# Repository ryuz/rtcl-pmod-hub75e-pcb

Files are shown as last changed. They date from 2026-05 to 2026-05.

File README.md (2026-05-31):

# HUB-75E LEDパネルを PMOD １個で駆動する基板

## 概要

HUB75E 形式の LED パネルを PMOD １個で駆動するための変換基板です。

Sipeed さんの [PMOD_HUB75E](https://wiki.sipeed.com/hardware/en/tang/tang-PMOD/FPGA_PMOD.html) だと PMOD コネクタが２個必要で、KV260 などのように PMOD コネクタが１個しかない FPGA ボードでは利用できません。

そこで PMOD 一個からデュアルエッジでデータを出して 64x64 の LED パネルを駆動するための基板を設計しました。

## 変換基板のイメージ

下記のような変換基板です。

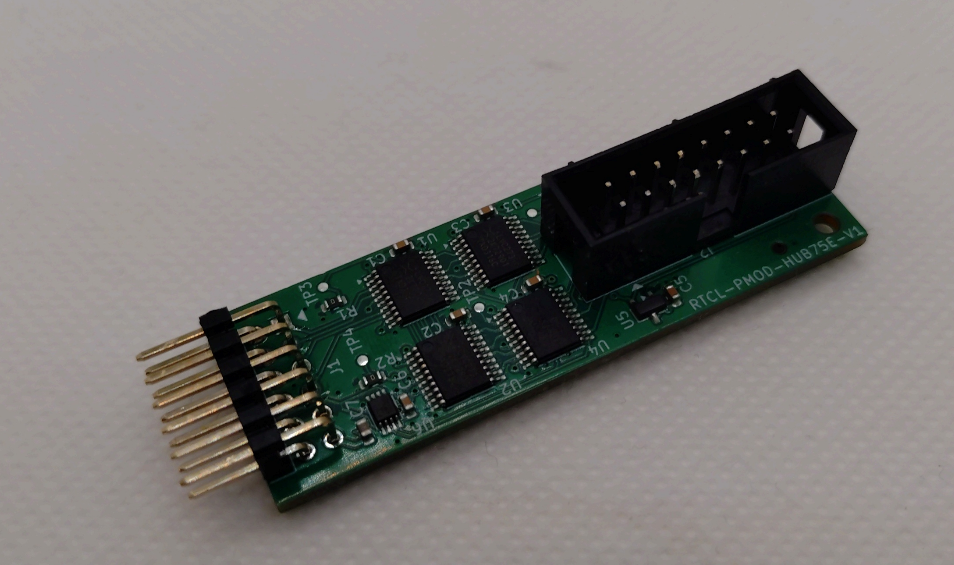
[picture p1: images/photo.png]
写真


PMOD コネクタ一個から HUB-75E LED パネルを駆動します。

## 各種データ

Ver1 の 回路図は[こちら](rtcl-pmod-hub75e-v1.pdf)です。

[KiCAD](https://www.kicad.org/) version 10.0.1 で設計しております。

[JLCPCB](https://jlcpcb.com/) さんの4層基板で製造を想定しております。

手元での試作は JLCPCB さんの PCBA で行っており、各自で製造される場合は必要に応じて部品を選定ください。

## 動作テスト

下記のプロジェクトなどで動作テストを行っております。

- https://github.com/ryuz/rtcl-designs/tree/develop/projects/kv260/kv260_rtcl_hub75e_sample

LED パネルの表示確認や各種パラメータの調整を行っております。

## 免責事項

本設計データは、研究開発用の試作実験に用するものであり、利用に際して発生した如何なる損害も作者は補償いたしませんので予めご了承ください。

## ライセンス(License)

本設計データは、[クリエイティブ・コモンズ 表示-非営利 4.0 国際 ライセンス](https://creativecommons.org/licenses/by-nc/4.0/deed.ja)の下で提供されています。

製造した本基板の販売や配布を行わない限りは、趣味や研究開発用途でご自由にお使いいただく事が出来ます。
また、商用に製造販売を希望される場合は、別途ライセンス契約を作者までご相談ください。

## 作者情報

渕上 竜司(Ryuji Fuchikami)
[リアルタイムコンピューティング研究所](https://rtc-lab.com/)

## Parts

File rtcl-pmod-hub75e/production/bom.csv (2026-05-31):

Designator | Footprint | Quantity | Value | LCSC Part #
C1, C2, C3, C4, C5, C6 | 0603 | 6 | 0.1uF
C7 | 0603 | 1 | 10uF
J1 | PH_02x06_2.54mm | 1 | PMOD | C124371
J2 | PH_02x08_2.54mm | 1 | HUB75E | C7430313
J3 | PinHeader_1x02_P2.54mm_Vertical | 1 | Conn_01x02
R1, R2 | 0603 | 2 | 0
R3 | 0603 | 1 | 10k
SW1 | SW_OS102011MS2QN1 | 1 | OS102011MS2QN1 | C221829
TP1, TP2, TP3, TP4 | TestPoint_Pad_D1.0mm | 4 | TestPoint
U1, U2, U3, U4 | TSSOP-20_4.4x6.5mm_P0.65mm | 4 | 74LVC273 | C456144
U5 | SOT-23-3 | 1 | APX803D-29SAG-7 | C460555
U6 | VSSOP-8_2.3x2mm_P0.5mm | 1 | SN74LVC2G86DCUR | C507252

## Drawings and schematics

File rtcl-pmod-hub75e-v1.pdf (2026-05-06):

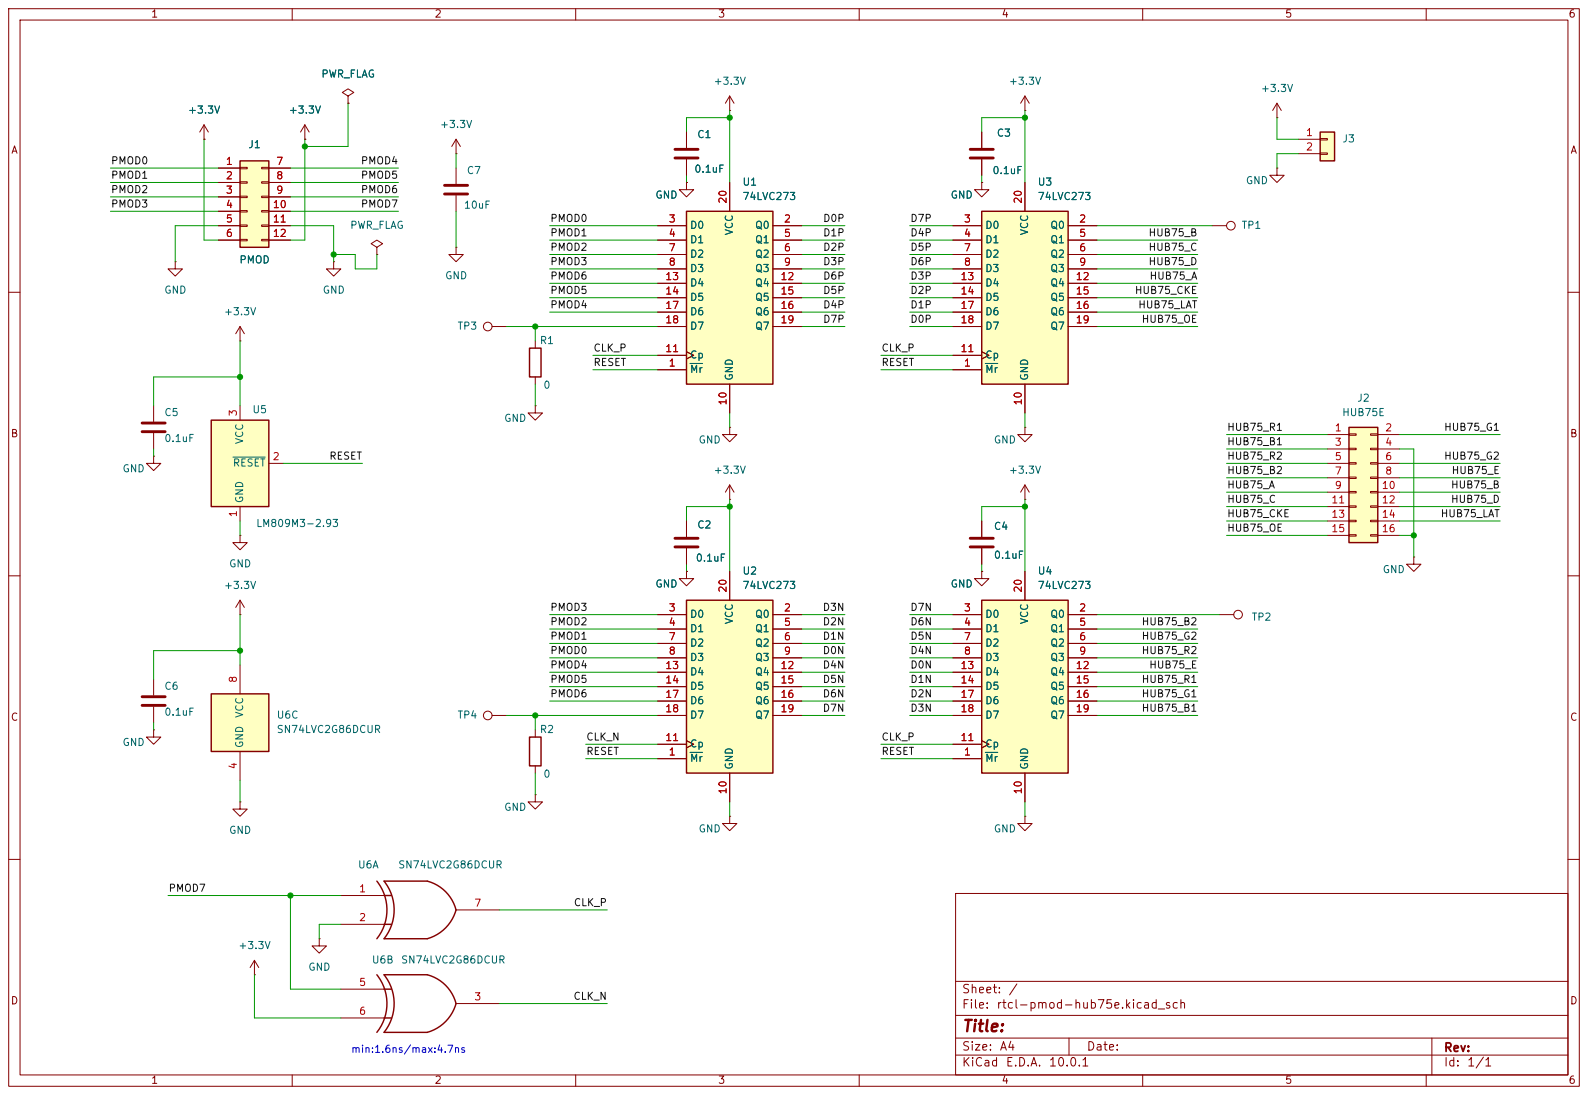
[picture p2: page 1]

Size: A4 | Rev:
KiCad E.D.A. 10.0.1 | Id: 1/1

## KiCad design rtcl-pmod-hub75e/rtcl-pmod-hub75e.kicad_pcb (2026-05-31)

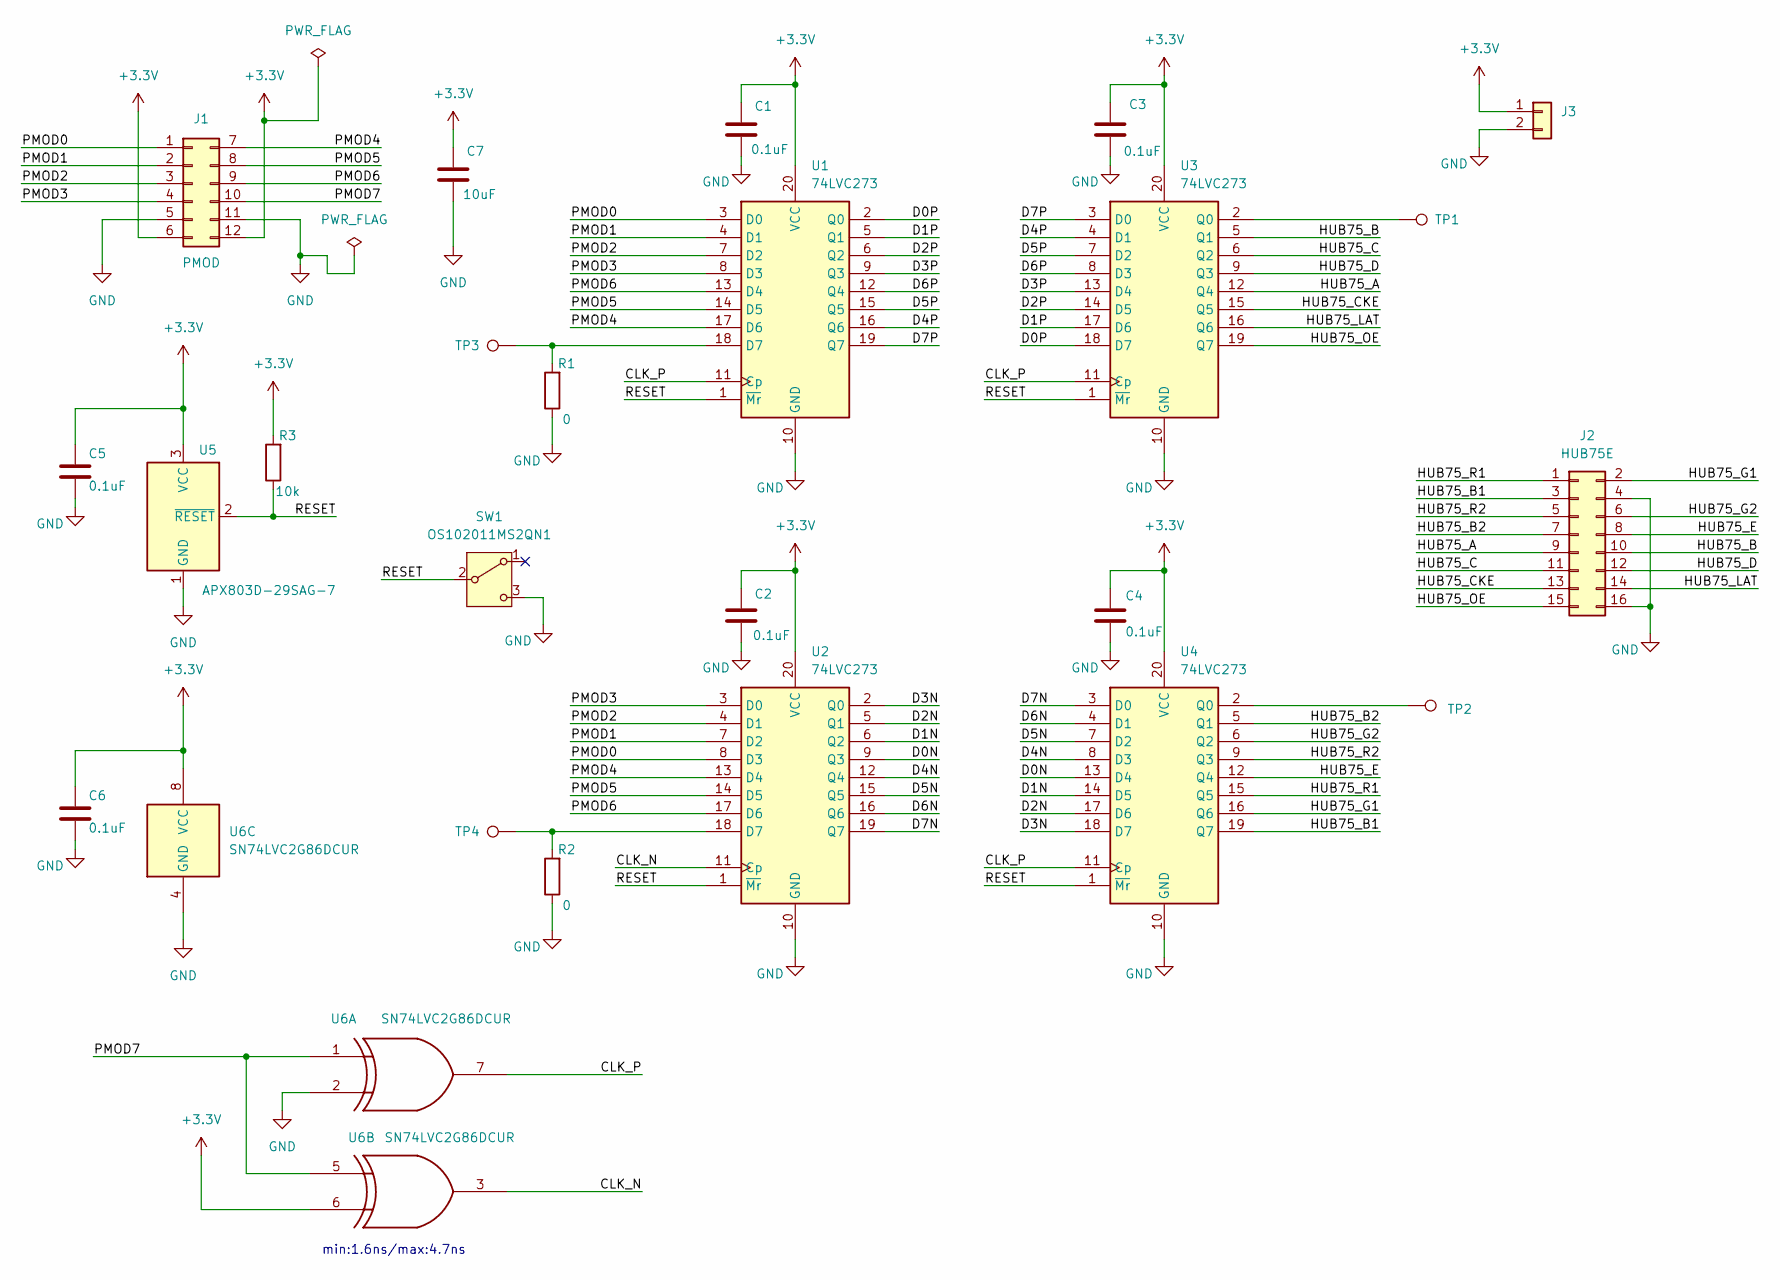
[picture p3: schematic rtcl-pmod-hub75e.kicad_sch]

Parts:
C1, C2, C3, C4, C5, C6: 0.1uF; C_0603_1608Metric
C7: 10uF; C_0603_1608Metric
J1: PMOD; PH_02x06_2.54mm; LCSC C124371
J2: HUB75E; PH_02x08_2.54mm; LCSC C7430313
J3: Conn_01x02; PinHeader_1x02_P2.54mm_Vertical
R1, R2: 0; R_0603_1608Metric
R3: 10k; R_0603_1608Metric
SW1: OS102011MS2QN1; SW_OS102011MS2QN1; LCSC C221829
TP1, TP2, TP3, TP4: TestPoint; TestPoint_Pad_D1.0mm
U1, U2, U3, U4: 74LVC273; TSSOP-20_4.4x6.5mm_P0.65mm; LCSC C456144
U5: APX803D-29SAG-7; SOT-23-3; LCSC C460555
U6: SN74LVC2G86DCUR; VSSOP-8_2.3x2mm_P0.5mm; LCSC C507252

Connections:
+3.3V: C1.1, C2.1, C3.1, C4.1, C5.1, C6.1, C7.1, J1.6, J1.12, J3.1, R3.2, U1.20 (VCC), U2.20 (VCC), U3.20 (VCC), U4.20 (VCC), U5.3 (VCC), U6.6, U6.8 (VCC)
/CLK_N: U2.11 (Cp), U6.3
/CLK_P: U1.11 (Cp), U3.11 (Cp), U4.11 (Cp), U6.7
/D0N: U2.9 (Q3), U4.13 (D4)
/D0P: U1.2 (Q0), U3.18 (D7)
/D1N: U2.6 (Q2), U4.14 (D5)
/D1P: U1.5 (Q1), U3.17 (D6)
/D2N: U2.5 (Q1), U4.17 (D6)
/D2P: U1.6 (Q2), U3.14 (D5)
/D3N: U2.2 (Q0), U4.18 (D7)
/D3P: U1.9 (Q3), U3.13 (D4)
/D4N: U2.12 (Q4), U4.8 (D3)
/D4P: U1.16 (Q6), U3.4 (D1)
/D5N: U2.15 (Q5), U4.7 (D2)
/D5P: U1.15 (Q5), U3.7 (D2)
/D6N: U2.16 (Q6), U4.4 (D1)
/D6P: U1.12 (Q4), U3.8 (D3)
/D7N: U2.19 (Q7), U4.3 (D0)
/D7P: U1.19 (Q7), U3.3 (D0)
/HUB75_A: J2.9, U3.12 (Q4)
/HUB75_B: J2.10, U3.5 (Q1)
/HUB75_B1: J2.3, U4.19 (Q7)
/HUB75_B2: J2.7, U4.5 (Q1)
/HUB75_C: J2.11, U3.6 (Q2)
/HUB75_CKE: J2.13, U3.15 (Q5)
/HUB75_D: J2.12, U3.9 (Q3)
/HUB75_E: J2.8, U4.12 (Q4)
/HUB75_G1: J2.2, U4.16 (Q6)
/HUB75_G2: J2.6, U4.6 (Q2)
/HUB75_LAT: J2.14, U3.16 (Q6)
/HUB75_OE: J2.15, U3.19 (Q7)
/HUB75_R1: J2.1, U4.15 (Q5)
/HUB75_R2: J2.5, U4.9 (Q3)
/PMOD0: J1.1, U1.3 (D0), U2.8 (D3)
/PMOD1: J1.2, U1.4 (D1), U2.7 (D2)
/PMOD2: J1.3, U1.7 (D2), U2.4 (D1)
/PMOD3: J1.4, U1.8 (D3), U2.3 (D0)
/PMOD4: J1.7, U1.17 (D6), U2.13 (D4)
/PMOD5: J1.8, U1.14 (D5), U2.14 (D5)
/PMOD6: J1.9, U1.13 (D4), U2.17 (D6)
/PMOD7: J1.10, U6.1, U6.5
/RESET: R3.1, SW1.2 (B), U1.1 (~Mr), U2.1 (~Mr), U3.1 (~Mr), U4.1 (~Mr), U5.2 (~RESET)
GND: C1.2, C2.2, C3.2, C4.2, C5.2, C6.2, C7.2, J1.5, J1.11, J2.4, J2.16, J3.2, R1.1, R2.1, SW1.3 (C), U1.10 (GND), U2.10 (GND), U3.10 (GND), U4.10 (GND), U5.1 (GND), U6.2, U6.4 (GND)
unnamed: R1.2, TP3.1 (1_1), U1.18 (D7)
unnamed: R2.2, TP4.1 (1_1), U2.18 (D7)
unnamed: TP1.1 (1_1), U3.2 (Q0)
unnamed: TP2.1 (1_1), U4.2 (Q0)

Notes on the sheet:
min:1.6ns/max:4.7ns

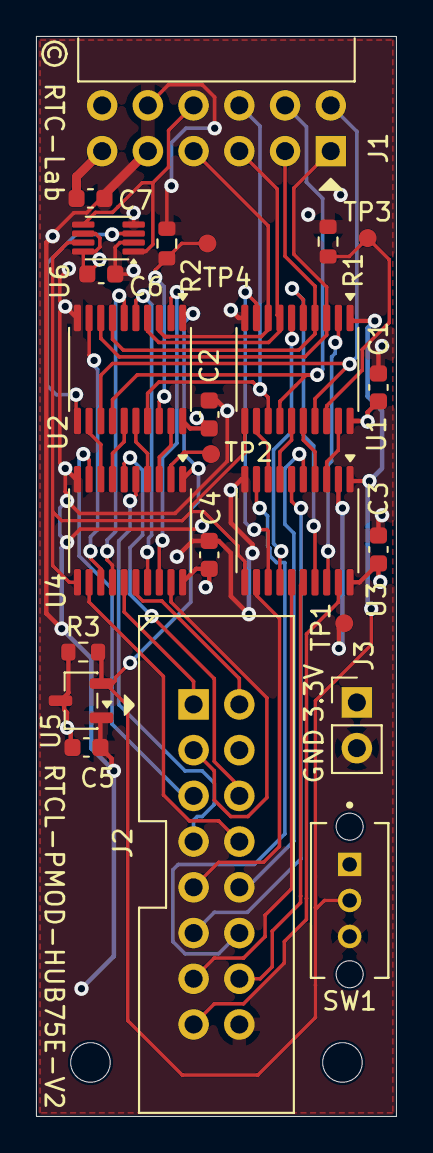
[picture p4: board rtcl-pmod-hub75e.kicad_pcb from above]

Board: 4 copper layers, 20.0 x 60.0 mm, 24 parts (0 on the bottom side), 47 nets.

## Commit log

2026-05-04 1st commit
    [rtcl-pmod-hub75e.kicad_pcb, rtcl-pmod-hub75e.kicad_sch]
2026-05-04 Update .gitignore and modify schematic for power symbols and designators
    [rtcl-pmod-hub75e.kicad_sch]
2026-05-05 Add footprints for PH_02x06_2.54mm and PH_02x08_2.54mm headers; update existing schematic properties
    [rtcl-pmod-hub75e.kicad_pcb, rtcl-pmod-hub75e.kicad_sch]
2026-05-05 Refactor PH_02x06_2.54mm.kicad_mod: Update properties, adjust pin positions, and modify silk screen lines for improved clarity and accuracy
    [rtcl-pmod-hub75e.kicad_pcb]
2026-05-05 Update design rules and footprint for PH_02x08_2.54mm header
    - Modified differential pair dimensions and DRC exclusions in the project configuration.
    - Adjusted various design rule checks (DRC) to change warnings to errors or ignore them as necessary.
    - Updated minimum clearance and hole clearance values for better manufacturability.
    - Changed track widths and via dimensions to accommodate new design requirements.
    - Revised the footprint for PH_02x08_2.54mm header, including repositioning properties and updating UUIDs for pads and lines.
    - Ensured all pads are correctly placed and sized for optimal performance.
    [rtcl-pmod-hub75e.kicad_pcb]
2026-05-05 Refactor code structure for improved readability and maintainability
    [rtcl-pmod-hub75e.kicad_pcb, rtcl-pmod-hub75e.kicad_sch]
2026-05-05 Update PCB design parameters and wire connections in the rtcl-pmod-hub75e project
    - Changed active layer from 0 to 2 in the project settings.
    - Cleared used designators in the project file for better clarity.
    - Adjusted multiple wire connection points in the schematic to correct coordinates for improved layout.
    - Updated label positions for various components to reflect new wire connections and ensure proper alignment.
    [rtcl-pmod-hub75e.kicad_pcb, rtcl-pmod-hub75e.kicad_sch]
2026-05-05 Update PCB layout settings: change active layer to 0 and adjust selection filter options
    [rtcl-pmod-hub75e.kicad_pcb]
2026-05-05 Update active layer and adjust wire positions in schematic
    - Changed active layer from 0 to 2 in the PCB layout.
    - Adjusted multiple wire coordinates in the schematic to correct alignment.
    - Updated label positions for various components to ensure proper placement.
    - Modified test point coordinates for better alignment with the design.
    [rtcl-pmod-hub75e.kicad_pcb, rtcl-pmod-hub75e.kicad_sch]
2026-05-05 Update selection filter and zone display mode in KiCad project file
    - Changed selection filter for footprints from true to false
    - Updated zone display mode from 0 to 1
    [rtcl-pmod-hub75e.kicad_pcb]
2026-05-05 Disable vias visibility in the PCB layout for the rtcl-pmod-hub75e project
    [rtcl-pmod-hub75e.kicad_pcb]
2026-05-05 Update selection filter settings in rtcl-pmod-hub75e.kicad_prl to enable footprints and vias
    [rtcl-pmod-hub75e.kicad_pcb]
2026-05-05 Update PCB and schematic files for rtcl-pmod-hub75e
    - Changed active layer from 2 to 5 in the PCB layout.
    - Modified visibility settings for text, tracks, and vias in the PCB layout.
    - Updated visible layers in the PCB layout.
    - Changed footprint references from "TestPoint" to "rtcl-pmod-hub75e" in the schematic.
    - Updated UUIDs for various elements in the PH_02x08_2.54mm footprint.
    - Added new footprint for TestPoint_Pad_D1.0mm.
    [rtcl-pmod-hub75e.kicad_pcb, rtcl-pmod-hub75e.kicad_sch]
2026-05-05 Update active layer and selection filter settings in KiCad project files
    [rtcl-pmod-hub75e.kicad_pcb]
2026-05-05 Update active layer and selection filter settings in PCB layout
    - Changed active layer from 0 to 4 for improved visibility.
    - Modified selection filter to disable dimensions, footprints, graphics, keepouts, other items, pads, text, and zones for a cleaner interface.
    [rtcl-pmod-hub75e.kicad_pcb]
2026-05-05 Update KiCad project files and component model for PH_02x06_2.54mm
    - Changed active layer in rtcl-pmod-hub75e.kicad_prl from 4 to 0.
    - Updated UUIDs for various properties and elements in PH_02x06_2.54mm.kicad_mod.
    - Added embedded model for PH_02x06_2.54mm component with specified offset, scale, and rotation.
    [rtcl-pmod-hub75e.kicad_pcb]
2026-05-05 Refactor KiCad project files: remove obsolete footprint PH_02x06_2.54mm, update PCB layout and schematic, and enable footprint visibility in selection filter settings.
    [rtcl-pmod-hub75e.kicad_pcb]
2026-05-05 Update selection filter to disable footprint selection in rtcl-pmod-hub75e.kicad_prl
    [rtcl-pmod-hub75e.kicad_pcb]
2026-05-05 Add LCSC properties for components in schematic
    [rtcl-pmod-hub75e.kicad_sch]
2026-05-05 Add production files including BOM, designators, netlist, positions, and PCB layout updates
    - Created BOM file with component details and LCSC part numbers.
    - Added designators for all components in the design.
    - Generated netlist for IPC format.
    - Included positions for components with coordinates and rotations.
    - Updated PCB layout with new component properties and visibility settings.
    - Adjusted solder mask clearance in project settings.
    [bom.csv, designators.csv, positions.csv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]
2026-05-05 Update PCB and PRL files: adjust capacitor position and modify active layer settings
    [rtcl-pmod-hub75e.kicad_pcb]
2026-05-15 Add README and image for HUB-75E LED panel PMOD board
2026-05-31 Add new footprints for SPDT switch and OS102011MS2QN1 switch
    - Created a new footprint for SPDT switch (SPDT_OS102011_CNK) with detailed pad and silk layer definitions.
    - Added a new footprint for OS102011MS2QN1 switch, including properties, pads, and 3D model reference.
    [rtcl-pmod-hub75e.kicad_pcb, rtcl-pmod-hub75e.kicad_sch]
2026-05-31 Update active layer in rtcl-pmod-hub75e.kicad_prl from 5 to 1
    [bom.csv, designators.csv, positions.csv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]
2026-05-31 Update README and add LCSC part number for OS102011MS2QN1 switch
    [bom.csv, rtcl-pmod-hub75e.kicad_pcb, rtcl-pmod-hub75e.kicad_sch]

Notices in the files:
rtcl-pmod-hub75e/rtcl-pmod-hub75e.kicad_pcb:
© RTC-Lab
